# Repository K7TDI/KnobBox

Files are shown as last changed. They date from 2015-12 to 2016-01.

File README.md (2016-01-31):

# KnobBox
K7TDI's hardware interface for SDR software

This is a hardware controller for SDR software such as SDR-Console and HDSDR.  It currently utilizes keyboard emulation for input into the software, but the goal of the project is to be entirely compatible with Kenwood CAT serial communication.  This is well implemented in SDR-Console, which is quickly becoming my favorite software to use.  However, by using an Adruino Pro Micro (Atmel 328p, compatible with the Leonardo), keyboard and mouse wheel emulation is easy, and this allows the KnobBox to be used with any software that supports those.

This project, aside from the PCB, uses all off the shelf hardware, most of it available from China on eBay.  The total cost if you go that route is around $30, depending on how many extra parts you order.

It consists of:

An Arduino Pro Micro

2 5 pin rotary encoders with push buttons

a 16x2 LCD display with HD44780 controller

An enclosure

A custom PCB

Some videos:
https://vimeo.com/150329712

https://vimeo.com/150324509

https://vimeo.com/150324508

https://vimeo.com/150324507

**Notice/Current issues**

This is NOT complete, and is a pain to assemble.  I've included issues and proposed fixes in the hardware folder.

The software is also completely incomplete.  This is addressed in the software folder.

I really hope to get feedback and help with this project.  I've been plugging away at it for months now, and learning a lot along the way.  I'm a masters student in health sciences with an undergrad in biology, I hope some of you that are more experienced with hardware design and especially coding will make contributions.

I hope you find what I've released here helpful, and at least a starting point for your own ideas.

If you like this and use it for your own project that you distribute, I'd appreciate it if you included a mention of my callsign (K7TDI) and a link to this repo.

**If you'd like to contact me:**
**k7tdi@technotechnician.com**

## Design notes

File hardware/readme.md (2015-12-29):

Here is the hardware.  TLDR is at the bottom.

I designed it in Eagle (pretty poorly) using the default libraries plus the Sparkfun and Adafruit libraries.  You can find them below.  I also made a custom library with some different pad sizes and shapes to make it easier to make the board.  If you use Eagle to make PCBs at home, I highly reccomend modifying the pads, especially the inside drill diameter.  Since you're drilling them out with whatever bit size you want anyway, you might as well leave more metal there and have a small dimple in the middle, which makes it way easier to square up the drill bit.

Sparkfun libraries: https://github.com/sparkfun/SparkFun-Eagle-Libraries

Adafruit libraries: https://github.com/adafruit/Adafruit-Eagle-Library

This is exactly what I used, so if you replicate it, it should work.  However, it can be improved, and when I have time I'll put up some new files with ideas for improvements I came up with while assembling it.  I'm sure someone more experienced could also do a complete overhaul on this and make it way better.  I've included some of my issues and ideas in the Issues file.

*TLDR: The eagle files use the SparkFun, Adafruit, and my libraries.  If you recreate this, it should work.  The Issues file has things I ran into while making and assembling it.*

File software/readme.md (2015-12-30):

Here are some example files that show what the hardware can do.  I've commented as much as possible in the code, although I make no promises that my thought process makes sense.

These make use of the LiquidCrystal library included with the Arduino IDE, and the Encoder library from PJRC, which is by far the best I've found.  That's available here:

http://www.pjrc.com/teensy/td_libs_Encoder.html

basic_function is an example of interfacing with the hardware and turning knobs.

basic_scrolling is a simple mouse wheel scroll emulator using the left encoder knob.

basic_HDSDR includes both mouse wheel scrolling and keyboard commands.

basic_CAT is a starting point for serial communications using Kenwood CAT commands, which are compatible with SDR-Console.

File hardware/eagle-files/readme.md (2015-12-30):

Here are the Eagle files for the KnobBox.  You'll also find my Eagle library here.  Go back and read the readme in the Hardware folder if you haven't yet.

About making the board:

I successfully made this using the toner transfer method with a Brother laser printer, HP photo paper, and Radio Shack etchant solution.  I haven't tried using any other printer, but at least with this combo, after printing I need to put the photo paper in a sealed container containing a little bit of acetone (not touching the paper) for about half an hour before I iron the paper onto the PCB.

I'm still getting the hang of all of it, so I tried to keep the traces as wide and widely spaced as possible.  I'm fairly sure these files are not within spec for production by a board house, but I'm sure it wouldn't be too hard to fix, and some awesome improvements in routing could be made with closer spaced traces and a ground plane.

These files are released under the GPL V3, info can be found in the LICENCE file

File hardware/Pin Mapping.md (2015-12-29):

I know my schematic sucks, so if you get lost, here are the important pins:

 Rotary Encoders:

Left Encoder:

  B -> TX (Arduino pin 0) (CCW)
  
  C -> GND
  
  A -> RX (Arduino pin 1) (CW)

Right Encoder:

  B -> 2 (CW)
  
  C -> GND
  
  A -> 3 (CCW)

LCD Backlight:

Pin 10 is connected to the base on an NPN transistor with a current limiting resistor (not sure if this is needed or not) of 100 ohms.  You can analogWrite to it and change the backlight brightness.

Everything Else:
On my KnobBox I broke out all the other pins to pin headers on the board.  You don't need to, but the pads are there in the eagle files.
I wound up leaving RAW and RST unconnected because I already had too much crap stuffed between the board and the back of the LCD at that spot.

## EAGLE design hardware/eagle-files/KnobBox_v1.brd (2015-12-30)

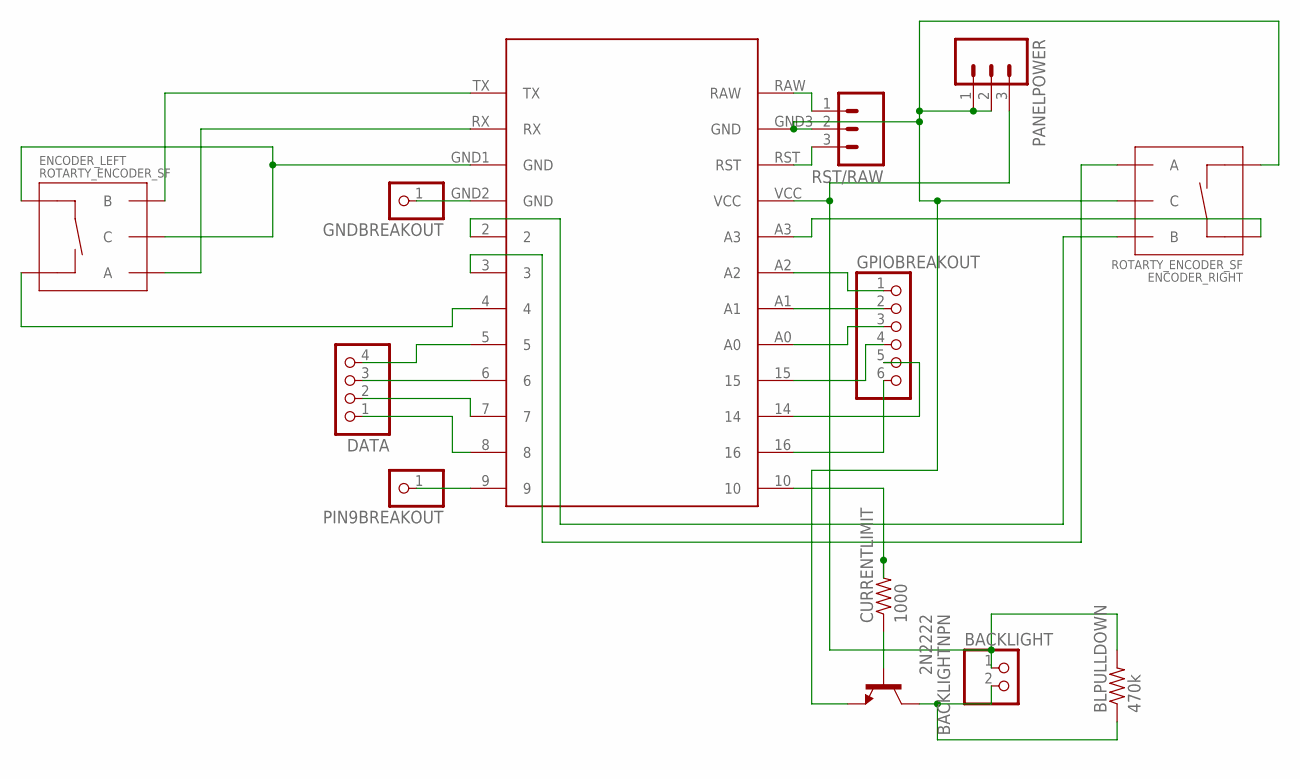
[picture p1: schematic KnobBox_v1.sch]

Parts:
BACKLIGHT: PINHD-1X2; 1X02
BACKLIGHTNPN: 2N2222; TO92-EBC-OVAL
BLPULLDOWN: 470k; AXIAL-0.4
CURRENTLIMIT: 1000; AXIAL-0.4
DATA: PINHD-1X4; 1X04
ENCODER_LEFT: ROTARTY_ENCODER_SF; ROTARY_ENC_SF_MOD
ENCODER_RIGHT: ROTARTY_ENCODER_SF; ROTARY_ENC_SF_MOD
GNDBREAKOUT: PINHD-1X1BIG; 1X01_MOD
GPIOBREAKOUT: PINHD-1X6; 1X06
PANELPOWER: M03PTH; 1X03
PIN9BREAKOUT: PINHD-1X1BIG; 1X01_MOD
PROMICRO: PROMICROROUND; PROMICRO
RST/RAW: M03PTH; 1X03

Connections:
unnamed: ENCODER_LEFT.B, PROMICRO.TX
unnamed: ENCODER_LEFT.A, PROMICRO.RX
unnamed: ENCODER_RIGHT.A, PROMICRO.3
unnamed: ENCODER_RIGHT.B, PROMICRO.2
unnamed: BACKLIGHTNPN.E, ENCODER_RIGHT.C, ENCODER_RIGHT.SW-, PANELPOWER.1, PANELPOWER.2, PROMICRO.GND3 (GND), RST/RAW.2
unnamed: ENCODER_LEFT.C, ENCODER_LEFT.SW+, PROMICRO.GND1 (GND)
unnamed: ENCODER_LEFT.SW-, PROMICRO.4
unnamed: ENCODER_RIGHT.SW+, PROMICRO.A3
unnamed: DATA.4, PROMICRO.5
unnamed: DATA.3, PROMICRO.6
unnamed: DATA.2, PROMICRO.7
unnamed: DATA.1, PROMICRO.8
unnamed: CURRENTLIMIT.P$2 (2), PROMICRO.10
unnamed: BACKLIGHTNPN.B, CURRENTLIMIT.P$1 (1)
unnamed: BACKLIGHT.1, BLPULLDOWN.P$2 (2), PANELPOWER.3, PROMICRO.VCC
unnamed: BACKLIGHT.2, BACKLIGHTNPN.C, BLPULLDOWN.P$1 (1)
unnamed: GPIOBREAKOUT.1, PROMICRO.A2
unnamed: GPIOBREAKOUT.2, PROMICRO.A1
unnamed: GPIOBREAKOUT.3, PROMICRO.A0
unnamed: GPIOBREAKOUT.4, PROMICRO.15
unnamed: GPIOBREAKOUT.5, PROMICRO.14
unnamed: GPIOBREAKOUT.6, PROMICRO.16
unnamed: PIN9BREAKOUT.1, PROMICRO.9
unnamed: PROMICRO.RAW, RST/RAW.1
unnamed: PROMICRO.RST, RST/RAW.3
unnamed: GNDBREAKOUT.1, PROMICRO.GND2 (GND)

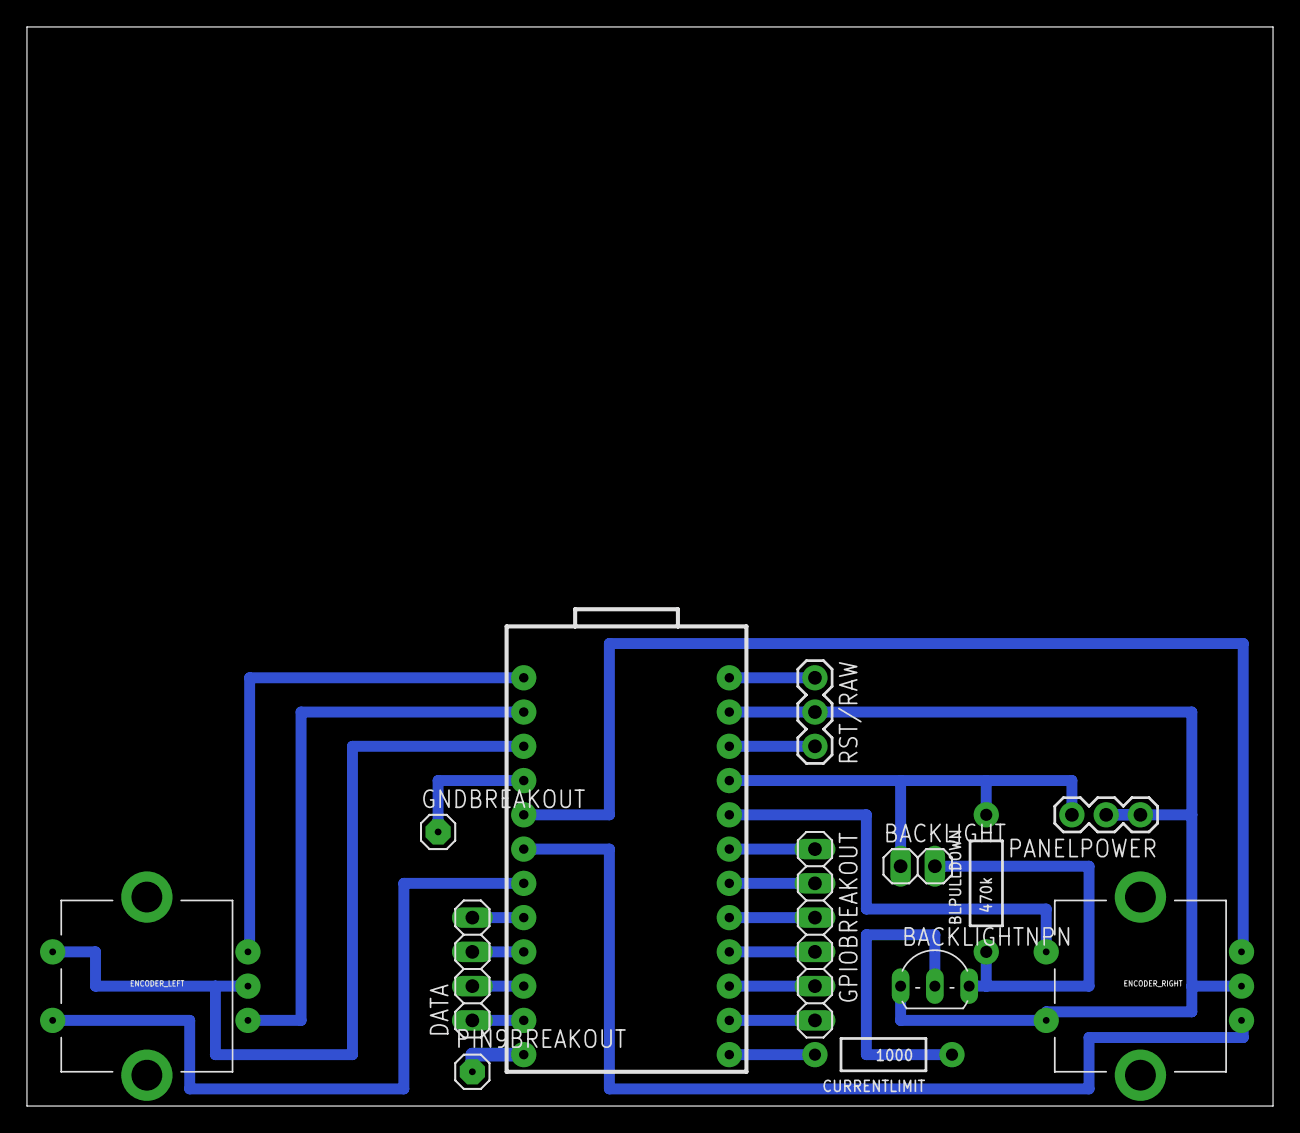
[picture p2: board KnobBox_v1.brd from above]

Board: 2 copper layers, 92.4 x 80.0 mm, 13 parts (0 on the bottom side), 26 nets.

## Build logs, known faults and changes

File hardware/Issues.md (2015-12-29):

Here are some current issues at the time of writing:

I'd highly reccomend doing your own research, especially around the enclosure.  The one used here is too small (mainly inside height) to hold everything.  I had to bend several of the pins at an angle to make the cables fit, although I think this can be easily remedied by making the board bigger to allow the use of 90 degree pin headers on all the connections.  There is still hardly any room between the top of the Arduino and the connections on the bottom of the LCD display the way it is now.  My plan for the next version, when I have time to make it, is to make the board the complete size of the bottom of the enclosure, and see if I can route everything while turning the arduino 90 degrees from where it is now.

Currently the board is about half the size it could be, because when I originally started designing the project, that was the biggest board I could make.  In addition to the ideas mentioned above, the new version will definately have a microUSB connector at the front.  I tried shoehorning a USB-B connector into the case and it just isn't going to happen (at least with my skills).

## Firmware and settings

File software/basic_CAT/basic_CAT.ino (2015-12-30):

/*
 * This is a development sketch for K7TDI's KnobBox
 * Check out https://github.com/K7TDI/KnobBox for more info
 * Copyright at end of file.
 * 
 * This sketch is super buggy, but an intro to how one can interface the Kenwood CAT interface with SDR-Console (http://sdr-radio.com/)
 * It has no tuning functionality, but I have tested sending frequencies using (for example) Serial.print("FA000155000000;") to tune
 * SDR-Console to 155mhz.
 * 
 * This sketch will display current frequency and mode of SDR-Console.  There's a function included (sendmode()) that would allow you
 * to change the mode as well, but it's been touch and go getting it to work so I've omitted using it here.
 * 
 * Issues:
 * Aside from the bugginess overall, there's nothing here to handle the number of digits of the frequency changing on the LCD.
 * If you change from 1mhz to 999khz, you will have extra characters still on the screen.
 * 
 * If you get a bunch of garbled stuff on the screen, toggle serial on and off in SDR-Console.
*/

#include <LiquidCrystal.h> //for display
#include <Encoder.h>// include the PRJC encoder library http://www.pjrc.com/teensy/td_libs_Encoder.html

Encoder lEnc(1,0); //setup left encoder
Encoder rEnc(2,3); //setup right encoder

//setup lcd
LiquidCrystal lcd(16,14,5,6,7,8); //set up lcd

//pins
int blpin = 10; //backlight pwm pin
int leftbutton = 4; //left button pin
int rightbutton = 21; //right button pin

//global variables
unsigned long cfreq = 0; //current frequency
int mode; //current mode
unsigned long elapsed; //elapsed time, basically 'old' time


void setup() {
  pinMode(4, INPUT_PULLUP); //set up the left button
  pinMode(17, INPUT_PULLUP); //set up the right button
  analogWrite(10, 150); //turn on the backlight to a fixed setting
  lcd.begin(16, 2); //start LCD

  Serial.begin(57600); //blazin' fast!
  
  splash(); //show splash screen

  
  while (!Serial) //wait for serial connection
  {
    lcd.setCursor(0, 0);
    lcd.print("  Waiting For   ");
    lcd.setCursor(0, 1);
    lcd.print("    Serial..    ");
  }
  lcd.clear();

cfreq = getfreq(); //set cfreq to the frequency of SDR-Console
mode = getmode(); //set mode to current mode

lcd.setCursor(0,0);
lcd.print(cfreq); //display the current frequency

lcd.setCursor(13,1); //move to the bottom right
lcd.print(modetxt(mode)); //display the current mode in a 3 character string

}


void loop()
{
  
unsigned long newmillis = millis(); //a variable to use for every cycle

  if ((newmillis - elapsed) >= 500) //every 500 milliseconds, this can be sped up by a lot, but I left it slow here.  SDR-Console doesn't seem to mind being hammered by 'FA;', but other things seem to not work as well.
  {
    long newfreq = getfreq(); //get the current frequency over serial
    int newmode = getmode(); //get the current mode over serial
    
    if (newfreq != cfreq); //if the frequency has changed
      {
        cfreq = newfreq; //update the global freqency variable
        lcd.setCursor(0,0); //move the cursor...
        lcd.print(cfreq); //show the new freqency
      }
    if (newmode != mode) //if the mode has changed... same as above
      {
        mode = newmode;
        lcd.setCursor(13,1);
        lcd.print(modetxt(mode));
      }
    elapsed = newmillis; //reset the timer
  }
  
}

/***************************************************************************** Functions *****************************************************************************/
long getfreq() //returns VFO A frequency as a long(Serial.parseInt() actually returns a long).  This could be avoided with better handling of the leading zeroes for most frequencies.
{

  Serial.print("FA;"); //send request

  if (Serial.available() > 13) //if we have a return
  {
    unsigned long gotfreq = Serial.parseInt(); //parse it
    if (Serial.read() == ';') //once we hit the ';', exit
    {
      return gotfreq;
    }
  }
  else
  {
    return 0;
  }
} //end getfreq()

int getmode() //get current mode from SDR-Console
{

  Serial.print("MD;"); //send request
  delay(10);
  if (Serial.available() > 2) //if we have a return
  {
    int gotmode = Serial.parseInt(); //parse that shit
    if (Serial.read() == ';') //once we hit the ';', exit
    {
      if (gotmode < 1 || gotmode > 10) //if we get weird shit for the mode
      {
        gotmode = 1; //stick it on LSB
      }
      return gotmode;
    }
  }
} //end getmode()

String modetxt(int mode) //return a 3 character string for a mode number according to the spec
{
  switch (mode)
  {
  case 1:
    return "LSB";
    break;
  case 2:
    return "USB";
    break;
  case 3:
    return " CW";
    break;
  case 4:
    return " FM";
    break;
  case 5:
    return " AM";
    break;
  case 6:
    return "FSK";
    break;
  case 7:
    return "CWR";
    break;
  case 8:
    return "TNE";
    break;
  case 9:
    return "FSR";
    break;
  case 10:
    return "SAM";
    break;
  default:
    return "MOD";
    break;

  }
} //endmodetxt

void incrementmode() //increments the mode up 1 when called. (requires global variable 'mode')
{

  int newmode = mode + 1; //add 1 to mode variable

  switch (newmode) //sets mode to something common if it's been set to kenwood 6-9 or 10 (synchronous AM)
  {
  case 6: //if the mode is FSK
    newmode = 1; //pretend it's AM so we roll over to LSB on toggle
    break;
  case 7: //if mode is reverse CW
    newmode = 3; //pretend it's CW
    break;
  case 8: //if mode is 'tune' (I don't know if this would actually happen)
    newmode = 5; //pretend it's AM
    break;
  case 9: // if it's reverse FSK
    newmode = 1; //same as above, pretend it's AM
    break;
  case 10: //if it's synchronous AM, which sdrconsole sends
    newmode = 5; //pretend it's AM, this one makes sense right?
    break;
  case 11: //we hit the button after being on SAM
    newmode = 1; //if we pretended SAM is the same as regular AM, we'd land on LSB (#1) after clicking
    break;
  default:
    newmode = newmode; //don't change it
    break;

  }
}
void sendmode(int mode) //send the mode variable
{
  Serial.print("MD");
  Serial.print(mode);
  Serial.print(";");

} //end sendmode()

void splash() //splash screen
{
  unsigned long startmillis = millis();
  lcd.clear();
  lcd.setCursor(5, 0);
  lcd.print("#DFP");
  while (millis() - startmillis < 2000)
  {
  }
  lcd.clear();
}


/*
    This program is free software: you can redistribute it and/or modify
    it under the terms of the GNU General Public License as published by
    the Free Software Foundation, either version 3 of the License, or
    (at your option) any later version.

    This program is distributed in the hope that it will be useful,
    but WITHOUT ANY WARRANTY; without even the implied warranty of
    MERCHANTABILITY or FITNESS FOR A PARTICULAR PURPOSE.  See the
    GNU General Public License for more details.

    You should have received a copy of the GNU General Public License
    along with this program.  If not, see <http://www.gnu.org/licenses/>.
*/

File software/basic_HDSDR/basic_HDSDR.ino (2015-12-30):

/*
 * This is a basic functionality sketch of K7TDI's KnobBox
 * Check out https://github.com/K7TDI/KnobBox 
 * Copyright info is at the bottom
 * 
 * This sketch sends a mouse scroll when the left encoder is turned, and command + up or down arrow when the right encoder is turned
 * These commands are designed to work with HDSDR http://www.hdsdr.de/
 * 
 * If you haven't already, look at the 'basic_scrolling.ino' sketch to get a better idea of what is going on.
 * This sketch does not use the LCD, but I left everything in to be uncommented if you want to use it for something.
 * 
 * Issues:
 * The encoders I'm using register a change halfway between notches.  Therefore this sketch gives me twice as many steps as I would expect.
*/

#include <Keyboard.h> //for keyboard emulation
#include <Mouse.h> //for mouse emulation
#include <LiquidCrystal.h> //for display
#include <Encoder.h>// include the PRJC encoder library http://www.pjrc.com/teensy/td_libs_Encoder.html

Encoder lEnc(1,0); //setup left encoder
Encoder rEnc(2,3); //setup right encoder

//LiquidCrystal lcd(16,14,5,6,7,8); //set up lcd

//pins
//int blpin = 10; //backlight pwm pin
int leftbutton = 4; //left button pin
int rightbutton = 17; //right button pin

//variables
long leftposition = 5000; //arbitrary, I found you can stuff at least 9x10^10 into the encoder object and everything works fine
long rightposition = 5000;


unsigned long timer1; //updated to the output of millis() every cycle
unsigned long elapsed; //elapsed time, basically 'old' time
unsigned long elapsed1; //another 'old' time variable
int ldifference; //this keeps track of the difference between the left position variable and the register of the encoder
int rdifference; //same as above

void setup() {
  pinMode(4, INPUT_PULLUP); //set up the left button
  pinMode(17, INPUT_PULLUP); //set up the right button
  //analogWrite(10, 150); //turn on the backlight to a fixed setting
  //lcd.begin(16, 2); //start LCD

  Mouse.begin();
  Keyboard.begin();
  
  lEnc.write(leftposition); //start the register at the above defined position
  rEnc.write(rightposition); //same as above
  
  //splash(); //show splash screen
}

void loop() {

  unsigned long newmillis = millis(); //a variable to use for every cycle
  timer1 = newmillis; //set the timer var to current time
  long newLpos = lEnc.read(); //put the current encoder position into a variable
  long newRpos = rEnc.read();
  
  
  if ((newmillis - elapsed) >= 50) //every 50 milliseconds
    {
      ldifference = newLpos - leftposition; //see if there's a difference
      rdifference = newRpos - rightposition;
    
      if(ldifference != 0) //if the left position has changed
        {
          sendLeft(ldifference); //send that difference through the function.
          leftposition = newLpos; //reset the left position
          ldifference = 0; //clear out the difference
        }
       if(rdifference != 0) //if the right position has changed... same as above
        {
          sendRight(rdifference);
          rightposition = newRpos;
          rdifference = 0;
        }
      elapsed = newmillis; //reset the timer
  }

  
  if ((newmillis - elapsed1) >= 5000) //every 5 seconds, reset positions to 500.  We're interested in the difference between updates, this makes it less likely to overflow the variables
  {
    elapsed1 = millis();
    leftposition = 5000; //set the left position back to 5000
    rightposition = 5000; //set the right position back to 5000
    lEnc.write(leftposition); //set the encoder register back to 5000
    rEnc.write(rightposition); //same as above
    elapsed1 = newmillis; //reset the timer
  }
}


void sendLeft(int ldiff) //This doesn't need to be a function at this point, but I like having it here for further changes
{
  Mouse.move(0,0,ldiff); //send it
}

void sendRight(int rdiff)
{
  Keyboard.press(128); //push the control button
  
  if (rdiff > 0) //if rdiff is a positive number
  {
    for (int i = 0; i < rdiff; i++) //run this command 'rdiff' times
    {
    Keyboard.write(218); //press up arrow
    }
  }
  if (rdiff < 0) //if rdiff is a negative number
  {
    for (int i = 0; i < -rdiff; i++) //run this command 'rdiff' times
    {
    Keyboard.write(217); //press down arrow
    }
  }
  Keyboard.release(128); //release the control button
}

/*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
    You should have received a copy of the GNU General Public License
    along with this program.  If not, see <http://www.gnu.org/licenses/>.
*/

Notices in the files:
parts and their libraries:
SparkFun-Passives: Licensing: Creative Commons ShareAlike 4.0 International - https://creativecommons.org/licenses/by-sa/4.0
